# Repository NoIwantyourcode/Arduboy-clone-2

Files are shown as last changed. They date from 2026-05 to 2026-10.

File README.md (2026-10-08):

# Arduboy-clone

This is a clone of a popular Arduino based, Gameboy style console known as the Arduboy!

# Why I made this

I have always wanted a game console, But my parents have never let me have one, Instead wanting to me to focus on my studies, So I decided to make this as a more clever rebellion (Don't worry, I asked them before designing this)

# Schematic Pictures


# PCB Routed pictures


# PCB rendered pictures



# Case pictures




# Assembled pictures
image (2)

# IRL pictures:



# Demo video

Here is the demo video link [https://youtu.be/vsxfW2zVnzc](https://youtu.be/vsxfW2zVnzc)
Heres the second demo video (with case) [https://youtube.com/shorts/UJCODutgSrg?si=xlWPpG5ztKTAeB8U](https://youtube.com/shorts/UJCODutgSrg?si=xlWPpG5ztKTAeB8U)

# Notes

Sadly this project does not work

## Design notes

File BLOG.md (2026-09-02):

# Blog

# What went wrong?
I fully assembled the project but ran into an issue where the USB port wouldn't work because my dumb ahh forgot to wire the ATMega32u4's VREF pin to 5v disabling the USB communication lines because the ATMega32u4 thought it was running off battery, hence the project didn't work and it was impossible to program the thing, further more, while trying to bridge the VREF pin to 5v, I shorted 2 pins straight to ground and fried the board. Now, Even though JLCPCB gives you 2 boards I couldn't swap all my components over to the other board because I lifted a pad while trying to swap the USB D+/D- Resistors as I had the wrong resistors on this made the board unusable.

# What can I do to prevent it from happening again?
DON'T RUSH PROJECTS, READ DATASHEETS CAREFULLY AND PLEASE DO YOUR RESEARCH BEFORE DESIGNING THE PROJECT

# Current picture of the Arduboy:


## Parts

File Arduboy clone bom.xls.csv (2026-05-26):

JLCPCB BOM Tool - BOM Matching
BOM name：bom-JLCPCB Assembly Order.xlsx
PCB Assembled Qty：2
Your BOM |  | Order Information
Top Designator | Warning | JLCPCB Part # | Product link | Lib Type | Qty | Source | Total Price ($)
BZ1 |  | C113159 | https://jlcpcb.com/partdetail/MurataElectronics-PKLCS1212E4001R1/C113159 | Extended | 2 | 2 JLCPCB | 1.7246
C1 |  | C19666 | https://jlcpcb.com/partdetail/20375-CL10A475KO8NNNC/C19666 | Basic | 20 | 20 JLCPCB | 0.22
C2 |  | C19702 | https://jlcpcb.com/partdetail/20411-CL10A106KP8NNNC/C19702 | Basic | 20 | 20 JLCPCB | 0.204
C3,C4 |  | C1653 | https://jlcpcb.com/partdetail/2005-CL10C220JB8NNNC/C1653 | Basic | 20 | 20 JLCPCB | 0.08
C5 |  | C76935 | https://jlcpcb.com/partdetail/MurataElectronics-GRM033R61A105ME44D/C76935 | Extended | 20 | 20 JLCPCB | 0.07
C10,C6,C7,C8,C9 | 1.The comment (0201X104K100NT) of this part does not match the one (0.1uF) provided in your BOM. Please confirm; | C284966 | https://jlcpcb.com/partdetail/270391-0201X104K100NT/C284966 | Extended | 22 | 22 JLCPCB | 0.0176
D1,D2 |  | C191023 | https://jlcpcb.com/partdetail/GuangdongHottech-1N5819WS/C191023 | Basic | 20 | 20 JLCPCB | 0.222
J1 |  | C2894897 | https://jlcpcb.com/partdetail/HCTL-HC_TYPE_C_16P01A/C2894897 | Extended | 2 | 2 JLCPCB | 0.197
L1 |  | C66536 | https://jlcpcb.com/partdetail/Sunlord-SWPA252010S4R7MT/C66536 | Extended | 6 | 6 JLCPCB | 0.3444
R1 | 1.The comment (FRC0603F3093TS) of this part does not match the one (309K) provided in your BOM. Please confirm; | C2999532 | https://jlcpcb.com/partdetail/FOJAN-FRC0603F3093TS/C2999532 | Extended | 20 | 20 JLCPCB | 0.024
R2,R3 | 1.The comment (0402WGF5101TCE) of this part does not match the one (5.1K) provided in your BOM. Please confirm; | C25905 | https://jlcpcb.com/partdetail/26648-0402WGF5101TCE/C25905 | Basic | 20 | 20 JLCPCB | 0.018
R4 | 1.The comment (FRC0603F9763TS) of this part does not match the one (976K) provided in your BOM. Please confirm; | C2933270 | https://jlcpcb.com/partdetail/FOJAN-FRC0603F9763TS/C2933270 | Extended | 20 | 20 JLCPCB | 0.026
R5,R8 | 1.The comment (0402WGF1002TCE) of this part does not match the one (10k) provided in your BOM. Please confirm; | C25744 | https://jlcpcb.com/partdetail/26487-0402WGF1002TCE/C25744 | Basic | 20 | 20 JLCPCB | 0.026
R6,R7 | 1.The comment (0402WGF2202TCE) of this part does not match the one (22k) provided in your BOM. Please confirm; | C25768 | https://jlcpcb.com/partdetail/26511-0402WGF2202TCE/C25768 | Basic | 20 | 20 JLCPCB | 0.018
U1 | 1.The comment (ATMEGA32U4-AU) of this part does not match the one (ATmega32U4-A) provided in your BOM. Please confirm; | C44854 | https://jlcpcb.com/partdetail/MicrochipTech-ATMEGA32U4AU/C44854 | Extended | 2 | 2 JLCPCB | 15.717
U2 |  | C511326 | https://jlcpcb.com/partdetail/MicrochipTech-MCP1640CT_ICHY/C511326 | Extended | 2 | 2 JLCPCB | 1.9044
Y1 |  | C280836 | https://jlcpcb.com/partdetail/NDK-NX2520SA_16MHZ_STD_CSW5/C280836 | Extended | 5 | 5 JLCPCB | 2.12
J2 |  | - | https://www.aliexpress.com/item/1005003484018034.html?curPageLogUid=WIlsbLS49aA5 |  | 1 | Aliexpress | 2.01
SW1,SW2,SW3,SW4,SW5,SW6,SW7 |  | - | https://www.aliexpress.com/item/10000000781310.html?curPageLogUid=7lWSm8DBpMAm |  | 7 | Aliexpress | 0.64
LiPO battery |  |  | https://www.aliexpress.com/item/1005009329027447.html?curPageLogUid=4NuF1B0cE9OK |  | 1 | Aliexpress | 6.71
M2 Nuts |  |  | https://www.aliexpress.com/item/1005009393815442.html?curPageLogUid=wT3CJPnsK6kE |  | 1 | Aliexpress | 1.02
M2 bolts |  |  | https://www.aliexpress.com/item/4000602853448.html?curPageLogUid=jOai6j2ESDHE |  | 1 | Aliexpress | 0.66
TP4056 board |  |  | https://www.aliexpress.com/item/1005006043031985.html?curPageLogUid=MHkBaMfIgoNx |  | 1 | Aliexpress | 0.79
 |  |  |  |  |  | Total Price | 118
 |  |  | *PCBA is used

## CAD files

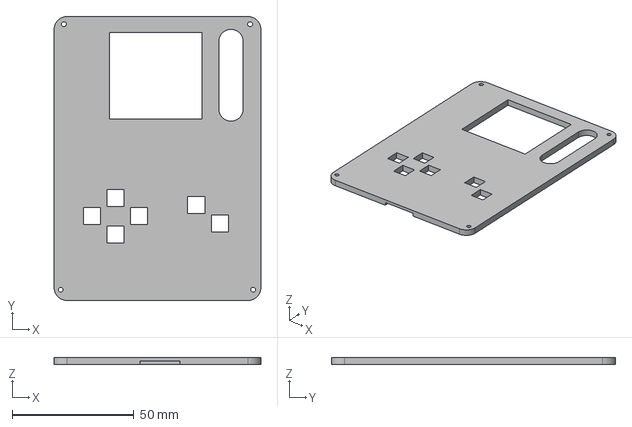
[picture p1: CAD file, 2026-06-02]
Case/Top case.step
85.1 x 116.8 x 3.00 mm

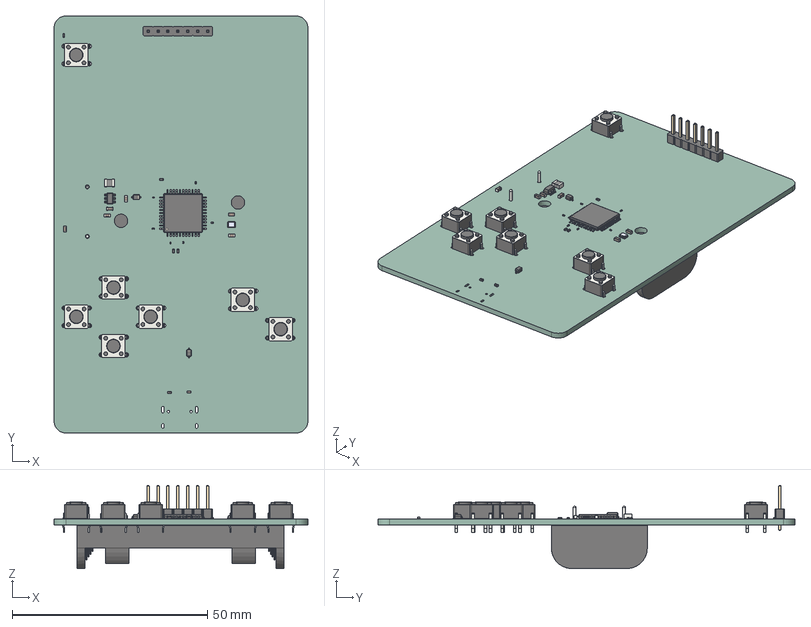
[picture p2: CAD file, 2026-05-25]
PCB files/Arduboy-clone.step
65.1 x 106.8 x 21.3 mm
R_0402_1005Metric x 4
C_0603_1608Metric x 6
D_SOD-323 x 2
C_0201_0603Metric x 6
L_1008_2520Metric
SW_PUSH_6mm x 7
Crystal_SMD_2.0x1.6mm
C_0402_1005Metric x 2
TQFP-44_10x10mm_P0.8mm
SOT-23-6
PinHeader_1x07_P2.54mm_Vertical
BatteryHolder_Keystone_2468_2xAAA
Arduboy-clone_PCB

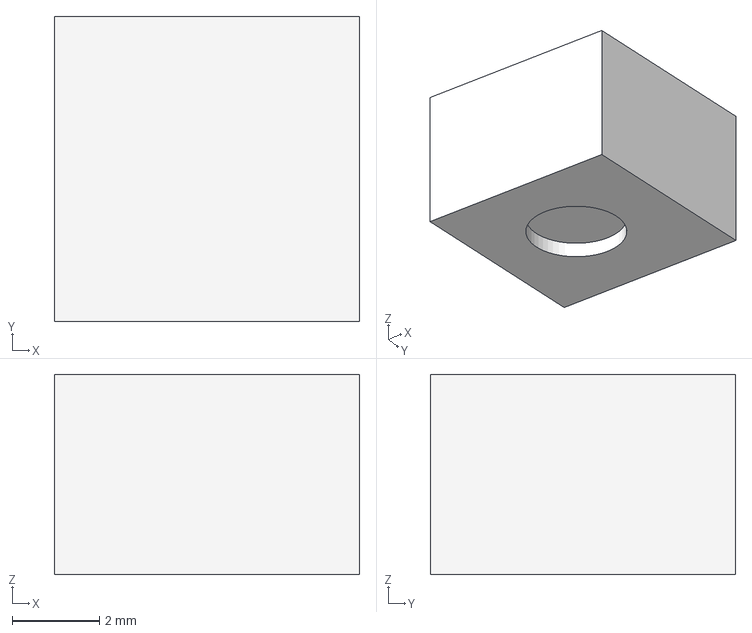
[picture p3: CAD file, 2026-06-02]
Case/Button (singular).step
7.00 x 7.00 x 4.60 mm

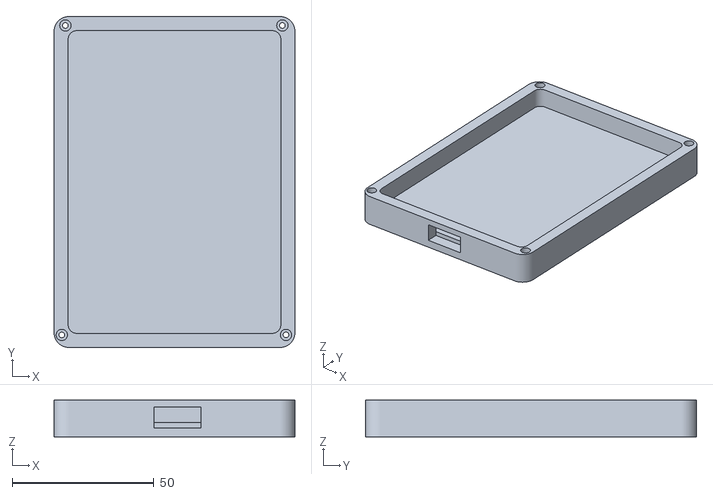
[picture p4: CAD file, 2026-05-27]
Case/Bottom case.stl
85.0 x 116.8 x 13.0

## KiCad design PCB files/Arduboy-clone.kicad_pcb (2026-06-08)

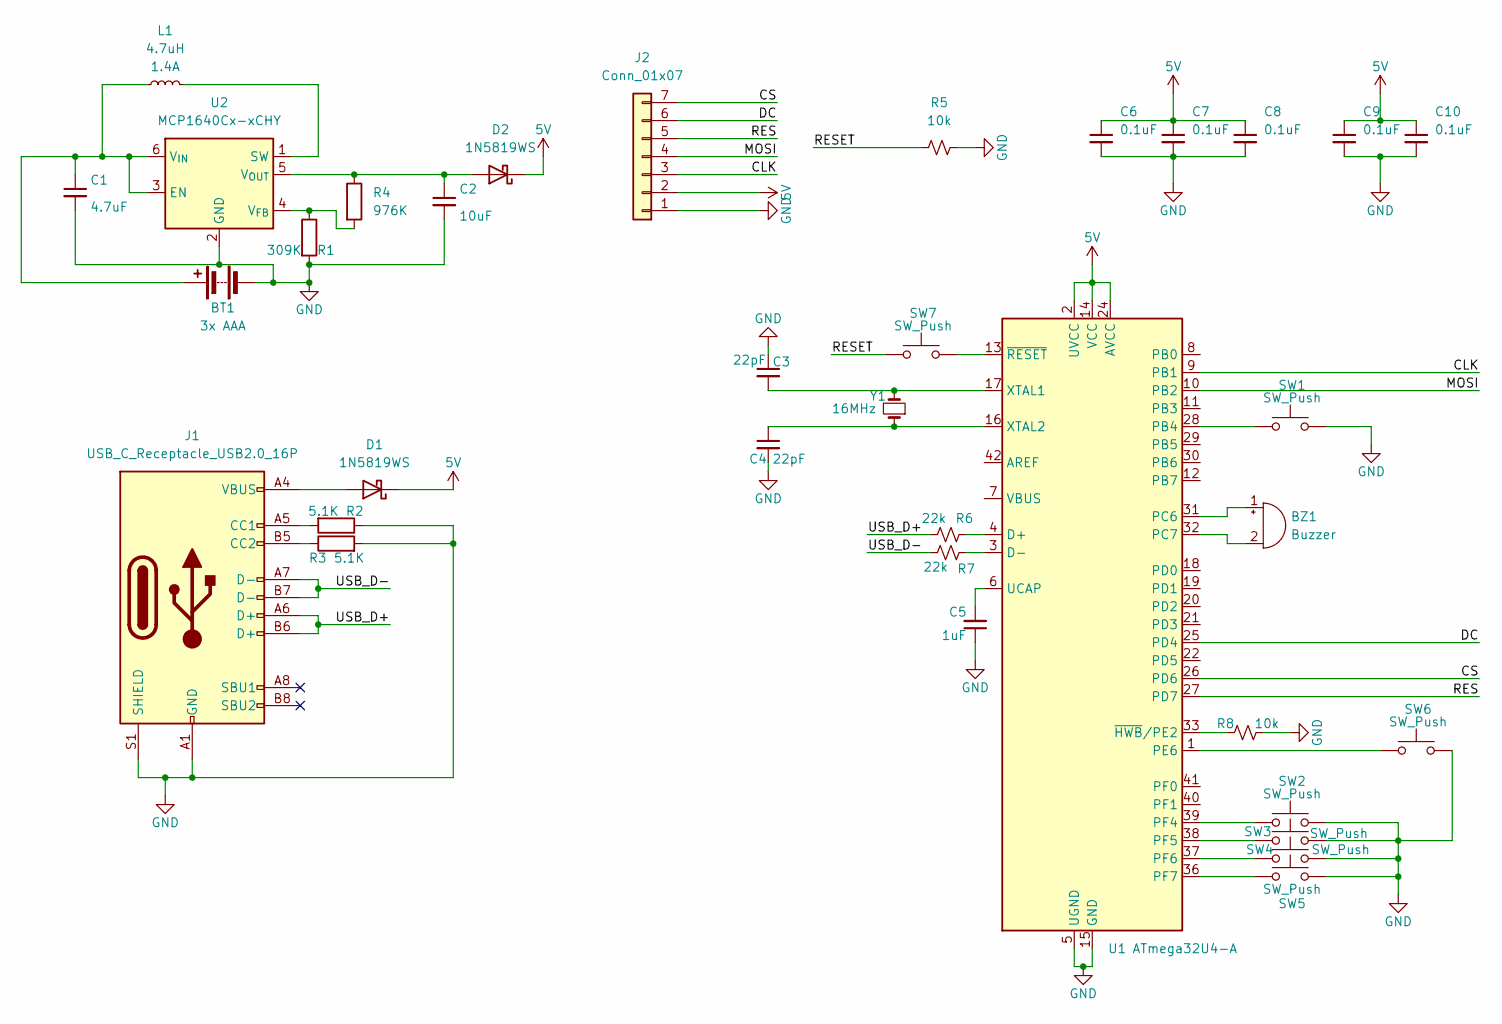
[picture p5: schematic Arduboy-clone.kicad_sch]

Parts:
BT1: 3x AAA; BatteryHolder_Keystone_2468_2xAAA
BZ1: Buzzer; Buzzer_Murata_PKLCS1212E
C1: 4.7uF; C_0603_1608Metric; Voltage 1kV; Tolerance 100%
C2: 10uF; C_0603_1608Metric; Voltage 1kV; Tolerance 100%
C3, C4: 22pF; C_0603_1608Metric; Voltage 1kV; Tolerance 100%
C5: 1uF; C_0201_0603Metric; Voltage 16V; Tolerance 10%
C6, C7, C8, C9, C10: 0.1uF; C_0201_0603Metric; Voltage 16V; Tolerance 10%
D1, D2: 1N5819WS; D_SOD-323
J1: USB_C_Receptacle_USB2.0_16P; USB_C_Receptacle_HCTL_HC-TYPE-C-16P-01A
J2: Conn_01x07; PinHeader_1x07_P2.54mm_Vertical
L1: 4.7uH; 1008_2520Metric
R1: 309K; C_0603_1608Metric
R2, R3: 5.1K; C_0402_1005Metric
R4: 976K; C_0603_1608Metric
R5, R8: 10k; R_0402_1005Metric
R6, R7: 22k; R_0402_1005Metric
SW1, SW2, SW3, SW4, SW5, SW6, SW7: SW_Push; SW_PUSH_6mm
U1: ATmega32U4-A; TQFP-44_10x10mm_P0.8mm
U2: MCP1640Cx-xCHY; SOT-23-6
Y1: 16MHz; Crystal_SMD_2.0x1.6mm

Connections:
5V: C6.1, C7.1, C8.1, C9.1, C10.1, D1.1 (K), D2.1 (K), J2.2, U1.2 (UVCC), U1.14 (VCC), U1.24 (AVCC), U1.34 (VCC), U1.44 (AVCC)
/CLK: J2.3, U1.9 (PB1)
/CS: J2.7, U1.26 (PD6)
/DC: J2.6, U1.25 (PD4)
/MOSI: J2.4, U1.10 (PB2)
/RES: J2.5, U1.27 (PD7)
/RESET: R5.1, SW7.1
/USB_D+: J1.A6 (D+), J1.B6 (D+), R6.1
/USB_D-: J1.A7 (D-), J1.B7 (D-), R7.1
GND: BT1.2 (-), C1.2, C2.2, C3.1, C4.2, C5.1, C6.2, C7.2, C8.2, C9.2, C10.2, J1.A1 (GND), J1.A12 (GND), J1.B1 (GND), J1.B12 (GND), J1.S1 (SHIELD), J2.1, R1.2, R2.1, R3.2, R5.2, R8.2, SW1.2, SW2.2, SW3.2, SW4.2, SW5.2, SW6.2, U1.5 (UGND), U1.15 (GND), U1.23 (GND), U1.35 (GND), U1.43 (GND), U2.2 (GND)
unnamed: BT1.1 (+), C1.1, L1.1, U2.3 (EN), U2.6 (V_{IN})
unnamed: BZ1.1 (+), U1.31 (PC6)
unnamed: BZ1.2 (-), U1.32 (PC7)
unnamed: D1.2 (A), J1.A4 (VBUS), J1.A9 (VBUS), J1.B4 (VBUS), J1.B9 (VBUS)
unnamed: C2.1, D2.2 (A), R4.1, U2.5 (V_{OUT})
unnamed: J1.A5 (CC1), R2.2
unnamed: J1.B5 (CC2), R3.1
unnamed: R6.2, U1.4 (D+)
unnamed: R7.2, U1.3 (D-)
unnamed: SW1.1, U1.28 (PB4)
unnamed: SW6.1, U1.1 (PE6)
unnamed: SW2.1, U1.39 (PF4)
unnamed: SW3.1, U1.38 (PF5)
unnamed: SW4.1, U1.37 (PF6)
unnamed: SW5.1, U1.36 (PF7)
unnamed: C5.2, U1.6 (UCAP)
unnamed: C3.2, U1.17 (XTAL1), Y1.2
unnamed: C4.1, U1.16 (XTAL2), Y1.1
unnamed: R8.1, U1.33 (~HWB/PE2)
unnamed: SW7.2, U1.13 (~RESET)
unnamed: L1.2, U2.1 (SW)
unnamed: R1.1, R4.2, U2.4 (V_{FB})

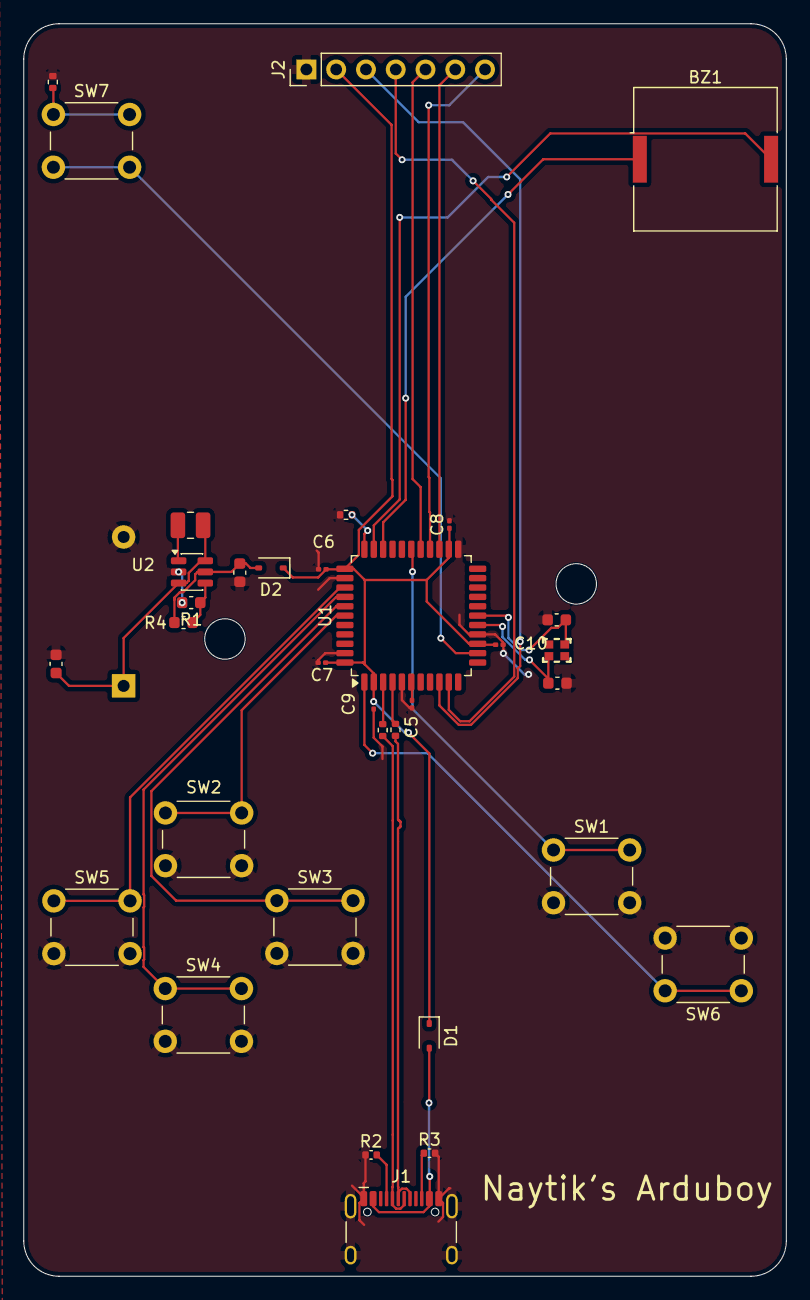
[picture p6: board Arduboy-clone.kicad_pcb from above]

Board: 2 copper layers, 65.1 x 106.8 mm, 35 parts (1 on the bottom side), 32 nets.

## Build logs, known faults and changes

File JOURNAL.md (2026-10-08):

**Total Time Spent: 13.5 hours**

# Added a case
Time: 1 hour
Date: October 8th 2026, Tuesday
I added a case to the project to finish it off.
heres a picture of the assembled case:


# Recieved, assembled and realised that this project won't work (old devlog, was supposed to be devlogged almost 2 months ago)
Time: 4 hours
Date: September 2nd 2026, Wednesday
I fully assembled the project but ran into an issue where the USB port wouldn't work because my dumb ahh forgot to wire the ATMega32u4's VREF pin to 5v disabling the USB communication lines because the ATMega32u4 thought it was running off battery, hence the project didn't work and it was impossible to program the thing, further more, while trying to bridge the VREF pin to 5v, I shorted 2 pins straight to ground and fried the board. Now, Even though JLCPCB gives you 2 boards I couldn't swap all my components over to the other board because I lifted a pad while trying to swap the USB D+/D- Resistors as I had the wrong resistors on this made the board unusable. 

And even if i had succeeded, I forgot to put down ICSP pin headers so I probably still would not have been able to program the chip

So in total, I ruined both boards because of bad design

heres a picture of the board:


# Routed the whole PCB, Finished BOM, Changed Display model.
Time: 4.5 hours
Date: May 24th 2026, Sunday
I completed routing the whole PCB and made the BOM and also made the case as well, When making the BOM I realised that the Adafruit display was too expensive and instead opted for a cheaper still 1.3 inch SPI display of aliexpress. 

Here is a picture of the routed PCB and the case:




# Completed the whole Schemetics!
Time: 3 hours
Date: May 24th 2026, Sunday
Today I completed finished the schematics and will now move onto the PCB routing,
I decided to use a AAA battery power source as its widely availible and easy to put!
I also used a standard Adafruit SSD1306 display!

heres a picture of the schematic:


# Added the MPU, Decoupling Capacitors, Display and Buttons!
Time: 1 hour
Date: May 23rd 2026, Saturday
Today I added the MPU and main display to the PCB, Routed all the buttons and added decoupling capacitors as well!

Here are some pictures of the current Schematics:


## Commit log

2026-05-23 Added MPU, Display and Decoupling Capacitors
    [Arduboy-clone.kicad_sch]
2026-05-23 Update JOURNAL.md with recent hardware additions
    Documented the addition of MPU, display, buttons, and capacitors.
2026-05-24 added display header
    [Arduboy-clone.kicad_sch]
2026-05-24 added power circuit, display, USB-C circuits
    I added the rest of the circuit and completed the whole schematic
    [Arduboy-clone.kicad_sch]
2026-05-24 Completely routed the board
    [Arduboy-clone.kicad_pcb, Arduboy-clone.kicad_sch]
2026-05-24 Generated Gerber File
    [Arduboy-clone.kicad_pcb, bom.csv, designators.csv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]
2026-05-24 Added Bom file and replaced display with a cheaper alternative
    [Arduboy clone bom.xls, Arduboy-clone.kicad_pcb, Arduboy-clone.kicad_sch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]
2026-05-24 Create Arduboy clone bom.xls.csv
    [Arduboy clone bom.xls.csv]
2026-05-24 Organized all the files into their respective folders
    [Arduboy clone bom.xls.csv, Arduboy-clone.kicad_pcb, Arduboy-clone.kicad_sch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]
2026-05-24 Added silkscreen customization
    [Arduboy clone bom.xls, Arduboy-clone.kicad_pcb]
2026-05-24 Added bom... again
    [Arduboy clone bom.xls.csv]
2026-05-24 Added bottom case
    I will add topcase after I get the PCB because I need accurate measurements
    [Bottom case.stl]
2026-05-24 added top case
    [Top case.stl]
2026-05-25 added better case
    [Arduboy-clone.step, Bottom case.stl, Top case.stl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]
2026-05-25 updated bom
    [Arduboy clone bom.xls.csv]
2026-05-26 added USB port
    [Bottom case.stl]
2026-05-26 changed Battery from AAA to LiPo (no case difference yet)
    [Arduboy clone bom.xls.csv]
2026-05-26 Added TP4056 charging board
    [Arduboy clone bom.xls.csv]
2026-05-26 Update Bottom case.stl
    [Bottom case.stl]
2026-05-27 added hole for speaker
    [Bottom case.stl, Top case.stl]
2026-06-02 added custom buttom tops
    [Button (singular).step, Top case.step, Top case.stl]
2026-06-08 Added silkscreen art
    [Arduboy-clone.kicad_pcb, Arduboy-clone.kicad_sch, bom.csv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]
